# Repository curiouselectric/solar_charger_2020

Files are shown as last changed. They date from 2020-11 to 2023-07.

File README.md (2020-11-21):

# solar_charger_2020
This is a single cell 18650 Lithium Polymer battery charging circuit using one cell PV module.

Based upon the BQ24210 800mA, single-input, single cell Li-ion Solar battery charger from Texas Instruments:

https://www.ti.com/sitesearch/docs/universalsearch.tsp?searchTerm=BQ24210#q=BQ24210&t=everything&linkId=1

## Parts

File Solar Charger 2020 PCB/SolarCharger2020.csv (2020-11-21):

Source: | G:\My Drive\Work - Kits\PRODUCTS\Prototype\Solar Charger 2020\GITHUB\solar_charger_2020\Solar Charger 2020 PCB\SolarCharger2020.sch
Date: | 21/11/2020 16:56:55
Tool: | Eeschema (5.1.0)-1
Generator: | C:\Program Files\KiCad\bin\scripting\plugins/bom_csv_grouped_by_value.py
Component Count: | 16
Individual Components:
Item | Qty | Reference(s) | Value | LibPart | Footprint | Datasheet | Cost | Description | Manufacturer | Manufacturer Part No | Notes | Supplier 1 | Supplier 1 Cost | Supplier 1 Part No | Supplier 2 | Supplier 2 Cost | Supplier 2 Part No
 |  | BT1 | 18650 LiIon Cell | Device:Battery_Cell | REInnovationFootprint:TH_LiIon_Holder |  |  | 18650 PCB mount holder | ~ | ~ | ~ | eBay | 0.50 | http://www.ebay.co.uk/itm/122466718109 | ~ | ~ | ~
 |  | C1 | 1uF | Device:CP | REInnovationFootprint:SM1206 |  |  | ~ | ~ | ~ | ~ | ~ | 0.1 | ~ | ~ | ~ | ~
 |  | C2 | 1uF | Device:CP | REInnovationFootprint:SM1206 |  |  | ~ | ~ | ~ | ~ | ~ | 0.10 | ~ | ~ | ~ | ~
 |  | D2 | CHG | SolarCharger2020-rescue:LED-Device | REInnovationFootprint:SM0805_LED |  |  | ~ | ~ | ~ | ~ | ~ | 0.05 | ~ | ~ | ~ | ~
 |  | D3 | PG | SolarCharger2020-rescue:LED-Device | REInnovationFootprint:SM0805_LED |  |  | ~ | ~ | ~ | ~ | ~ | 0.05 | ~ | ~ | ~ | ~
 |  | F1 | 1A | Device:Fuse | REInnovationFootprint:SM_FSMD | ~
 |  | LG1 | LOGO1 | Connector_Generic:Conn_01x01 | CuriousElectric3:2019_011_16_CuriousElectricCompany_Logo_Round_Logo_No_words_KiCAD_10mm_PCBLogo
 |  | LG2 | LOGO2 | Connector_Generic:Conn_01x01 | CuriousElectric3:TCEC_Words_13mm
 |  | P1 | LiPo OUTPUT | Connector_Generic:Conn_01x02 | REInnovationFootprint:SIL_2_screw_+_JST_2mm
 |  | P3 | PV INPUT | Connector_Generic:Conn_01x02 | REInnovationFootprint:SIL_2_screw_+_JST_2mm
 |  | PCB1 | PCB | Connector_Generic:Conn_01x01 | REInnovationFootprint:PCB_SolarChargerPCB40x80
 |  | R1 | 1k | Device:R | REInnovationFootprint:SM0805 |  |  | ~ | ~ | ~ | ~ | ~ | 0.01 | ~ | ~ | ~ | ~
 |  | R2 | 100k | Device:R | REInnovationFootprint:SM0805 |  |  | ~ | ~ | ~ | ~ | ~ | 0.01 | ~ | ~ | ~ | ~
 |  | R3 | 2.2k | Device:R | REInnovationFootprint:SM0805 |  |  | ~ | ~ | ~ | ~ | ~ | 0.01 | ~ | ~ | ~ | ~
 |  | R4 | 2.2k | Device:R | REInnovationFootprint:SM0805 |  |  | ~ | ~ | ~ | ~ | ~ | 0.01 | ~ | ~ | ~ | ~
 |  | U1 | BQ24210 | matts_components:BQ24210 | REInnovationFootprint:SM_WSON-10-2x3 | http://www.ti.com/lit/ds/symlink/bq24210.pdf | ~ | LiIon Charger 800mA PV Input | Texas Instruments | BQ24210 | ~ | RS | 2.88 | 742-2836 | ~ | ~ | ~
Collated Components:
Item | Qty | Reference(s) | Value | LibPart | Footprint | Datasheet | Cost | Description | Manufacturer | Manufacturer Part No | Notes | Supplier 1 | Supplier 1 Cost | Supplier 1 Part No | Supplier 2 | Supplier 2 Cost | Supplier 2 Part No
1 | 1 | BT1 | 18650 LiIon Cell | Device:Battery_Cell | REInnovationFootprint:TH_LiIon_Holder |  |  | 18650 PCB mount holder | ~ | ~ | ~ | eBay | 0.50 | http://www.ebay.co.uk/itm/122466718109 | ~ | ~ | ~
2 | 2 | C1, C2 | 1uF | Device:CP | REInnovationFootprint:SM1206 |  |  | ~ | ~ | ~ | ~ | ~ | 0.1 | ~ | ~ | ~ | ~
3 | 1 | D2 | CHG | SolarCharger2020-rescue:LED-Device | REInnovationFootprint:SM0805_LED |  |  | ~ | ~ | ~ | ~ | ~ | 0.05 | ~ | ~ | ~ | ~
4 | 1 | D3 | PG | SolarCharger2020-rescue:LED-Device | REInnovationFootprint:SM0805_LED |  |  | ~ | ~ | ~ | ~ | ~ | 0.05 | ~ | ~ | ~ | ~
5 | 1 | F1 | 1A | Device:Fuse | REInnovationFootprint:SM_FSMD | ~
6 | 1 | LG1 | LOGO1 | Connector_Generic:Conn_01x01 | CuriousElectric3:2019_011_16_CuriousElectricCompany_Logo_Round_Logo_No_words_KiCAD_10mm_PCBLogo
7 | 1 | LG2 | LOGO2 | Connector_Generic:Conn_01x01 | CuriousElectric3:TCEC_Words_13mm
8 | 1 | P1 | LiPo OUTPUT | Connector_Generic:Conn_01x02 | REInnovationFootprint:SIL_2_screw_+_JST_2mm
9 | 1 | P3 | PV INPUT | Connector_Generic:Conn_01x02 | REInnovationFootprint:SIL_2_screw_+_JST_2mm
10 | 1 | PCB1 | PCB | Connector_Generic:Conn_01x01 | REInnovationFootprint:PCB_SolarChargerPCB40x80
11 | 1 | R1 | 1k | Device:R | REInnovationFootprint:SM0805 |  |  | ~ | ~ | ~ | ~ | ~ | 0.01 | ~ | ~ | ~ | ~
12 | 1 | R2 | 100k | Device:R | REInnovationFootprint:SM0805 |  |  | ~ | ~ | ~ | ~ | ~ | 0.01 | ~ | ~ | ~ | ~
13 | 2 | R3, R4 | 2.2k | Device:R | REInnovationFootprint:SM0805 |  |  | ~ | ~ | ~ | ~ | ~ | 0.01 | ~ | ~ | ~ | ~
14 | 1 | U1 | BQ24210 | matts_components:BQ24210 | REInnovationFootprint:SM_WSON-10-2x3 | http://www.ti.com/lit/ds/symlink/bq24210.pdf | ~ | LiIon Charger 800mA PV Input | Texas Instruments | BQ24210 | ~ | RS | 2.88 | 742-2836 | ~ | ~ | ~

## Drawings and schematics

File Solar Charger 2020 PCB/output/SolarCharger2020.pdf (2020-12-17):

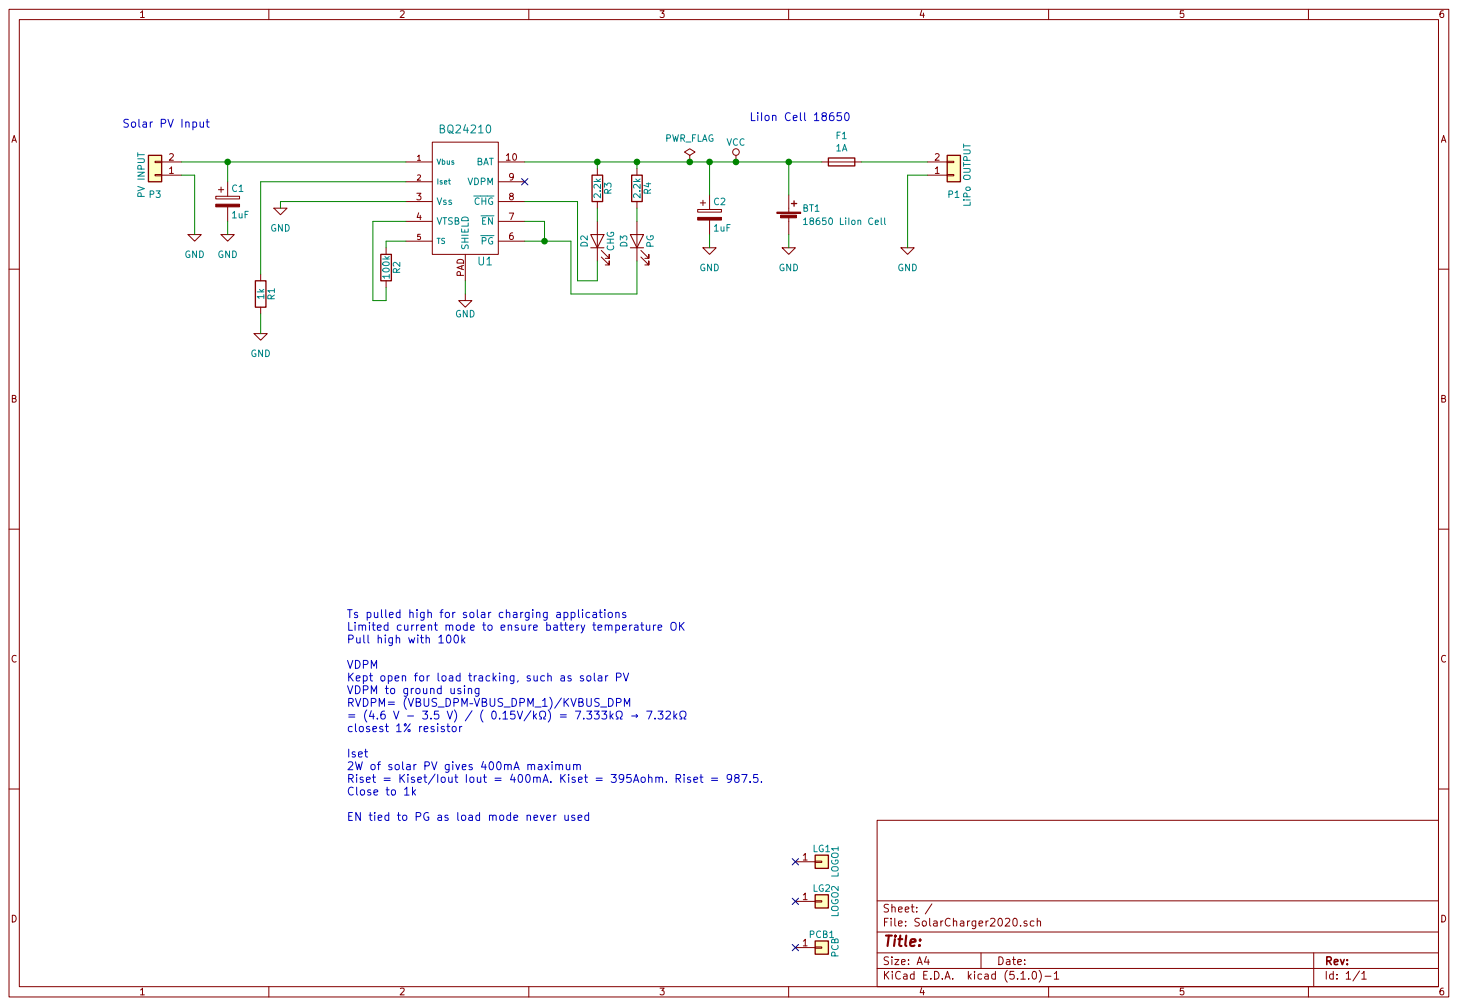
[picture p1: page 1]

Ts pulled high for solar charging applications
Limited current mode to ensure battery temperature OK
Pull high with 100k VDPM

Kept open for load tracking, such as solar PV
VDPM to ground using
RVDPM= (VBUS_DPMVBUS_DPM_1)/KVBUS_DPM

Iset 2W of solar PV gives 400mA maximum

Riset = Kiset/Iout Iout = 400mA. Kiset = 395Aohm. Riset = 987.5.
Close to 1k

EN tied to PG as load mode never used

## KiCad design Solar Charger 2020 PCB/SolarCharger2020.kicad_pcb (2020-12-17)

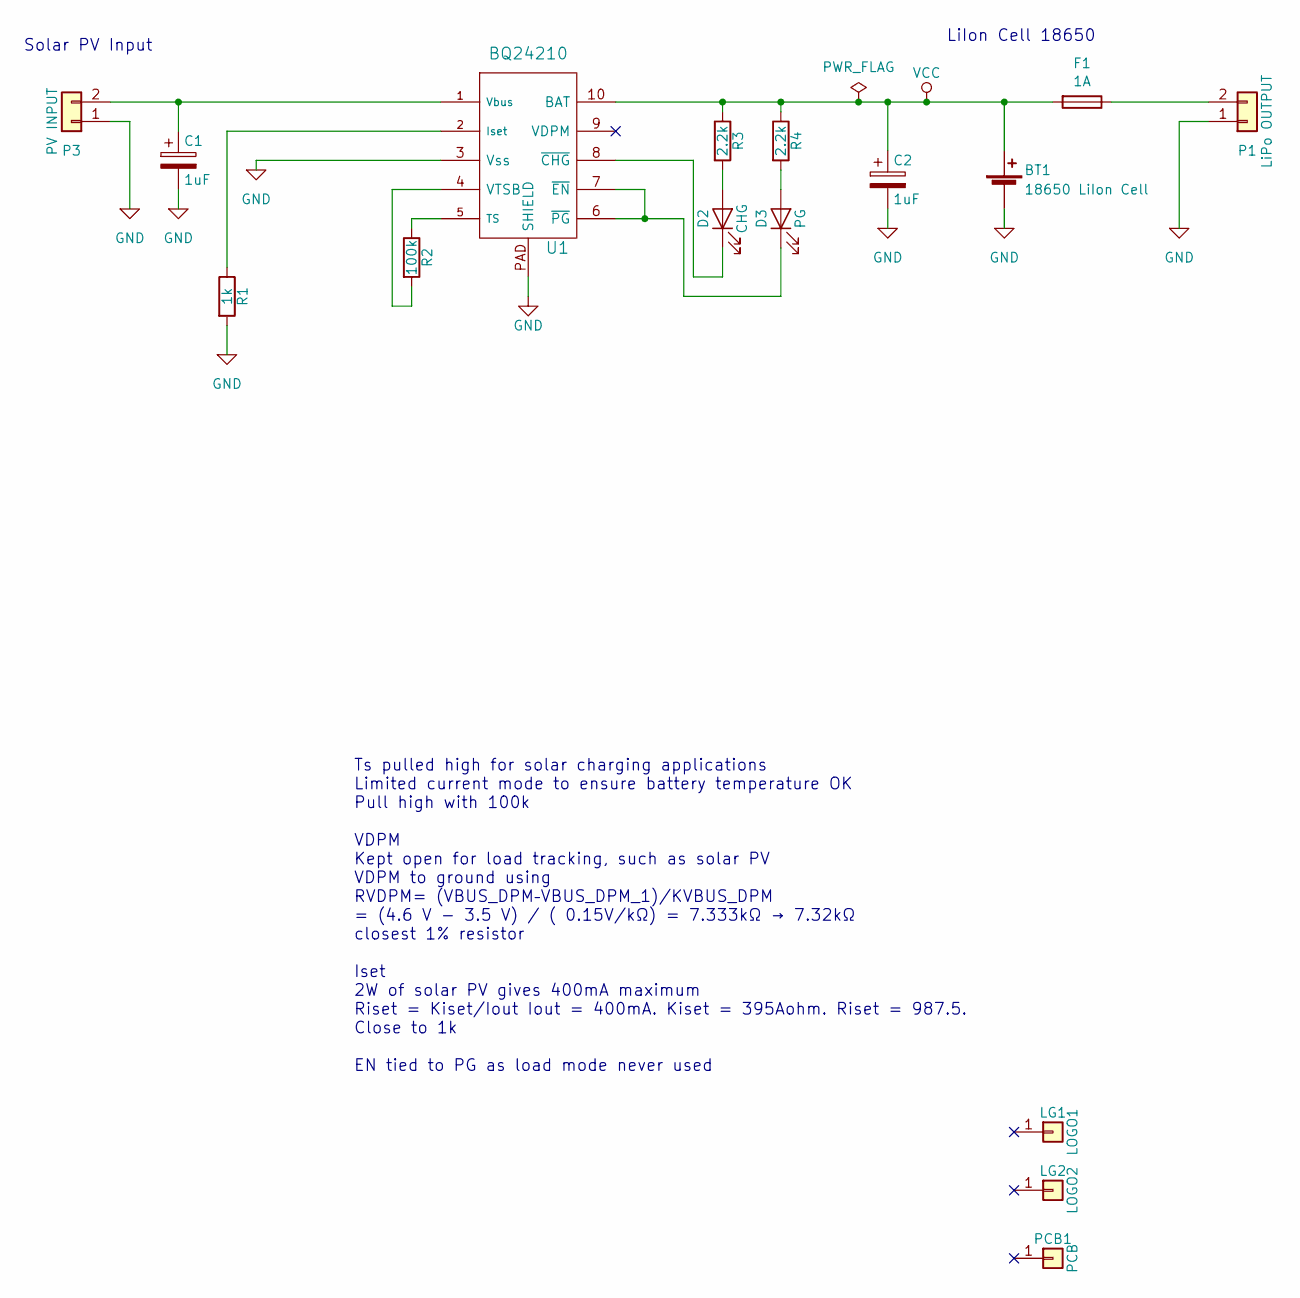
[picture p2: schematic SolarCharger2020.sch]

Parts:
BT1: 18650 LiIon Cell; TH_LiIon_Holder
C1, C2: 1uF; SM1206
D2: CHG; SM0805_LED
D3: PG; SM0805_LED
F1: 1A; SM_FSMD
LG1: LOGO1; 2019_011_16_CuriousElectricCompany_Logo_Round_Logo_No_words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
LG2: LOGO2; TCEC_Words_13mm
P1: LiPo OUTPUT; SIL_2_screw_+_JST_2mm
P3: PV INPUT; SIL_2_screw_+_JST_2mm
PCB1: PCB; PCB_SolarChargerPCB40x80
R1: 1k; SM0805
R2: 100k; SM0805
R3, R4: 2.2k; SM0805
U1: BQ24210; SM_WSON-10-2x3; Manufacturer Part No BQ24210

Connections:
GND: BT1.2 (-), C1.2, C2.2, P1.1, P3.1, R1.2, U1.3 (Vss), U1.PAD (SHIELD)
unnamed: C1.1, P3.2, U1.1 (Vbus)
unnamed: D2.1 (A), R3.2
unnamed: D2.2 (K), U1.8 (~CHG)
unnamed: D3.1 (A), R4.2
unnamed: D3.2 (K), U1.6 (~PG), U1.7 (~EN)
unnamed: F1.1, P1.2
unnamed: R1.1, U1.2 (Iset)
unnamed: R2.1, U1.5 (TS)
unnamed: R2.2, U1.4 (VTSB)
VCC: BT1.1 (+), C2.1, F1.2, R3.1, R4.1, U1.10 (BAT)

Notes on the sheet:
Solar PV Input
LiIon Cell 18650
Ts pulled high for solar charging applications Limited current mode to ensure battery temperature OK Pull high with 100k VDPM Kept open for load tracking, such as solar PV VDPM to ground using RVDPM= (VBUS_DPM–VBUS_DPM_1)/KVBUS_DPM = (4.6 V - 3.5 V) / ( 0.15V/kΩ) = 7.333kΩ → 7.32kΩ closest 1% resis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

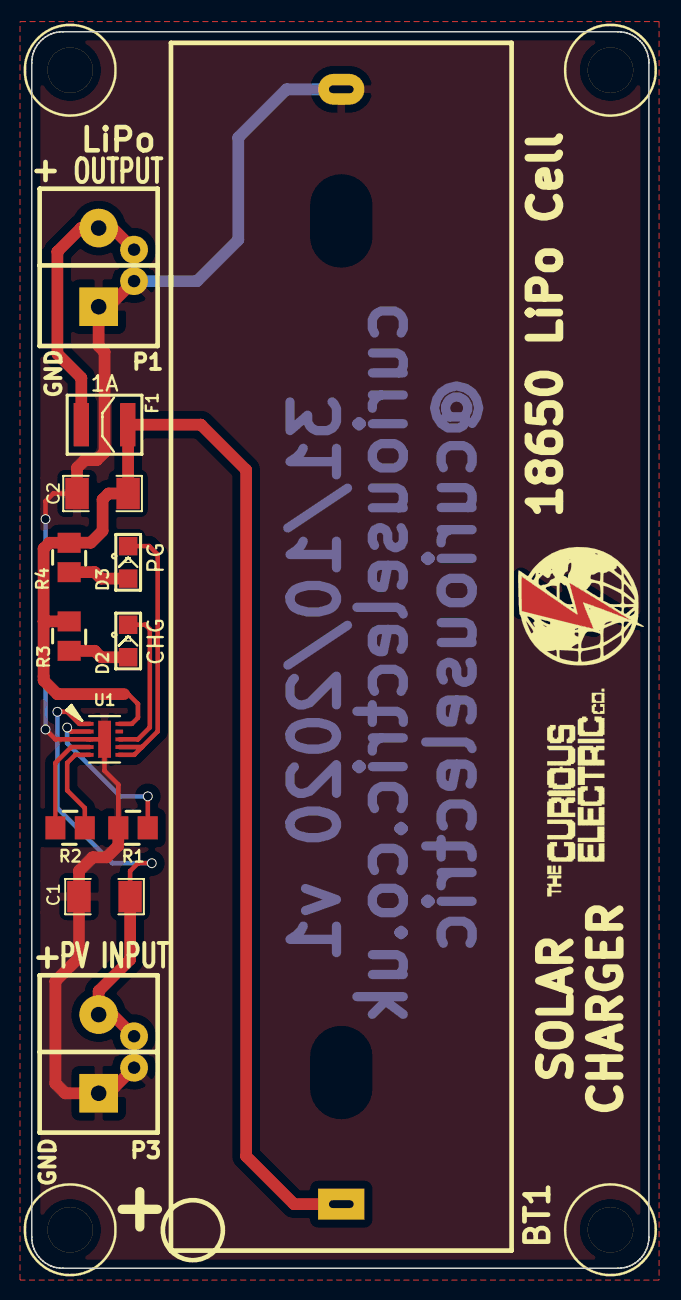
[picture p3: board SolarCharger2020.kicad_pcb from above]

Board: 2 copper layers, 39.9 x 79.9 mm, 16 parts (1 on the bottom side), 11 nets.

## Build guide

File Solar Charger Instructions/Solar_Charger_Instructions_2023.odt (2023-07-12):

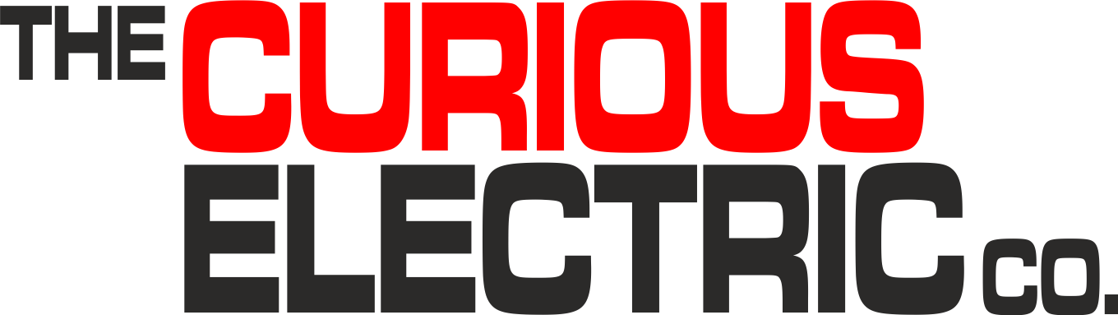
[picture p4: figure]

| BQ24210 Solar Charger Instructions

Date: | 12/7/2023 | Version: | 1.1 | By: | Matt Little

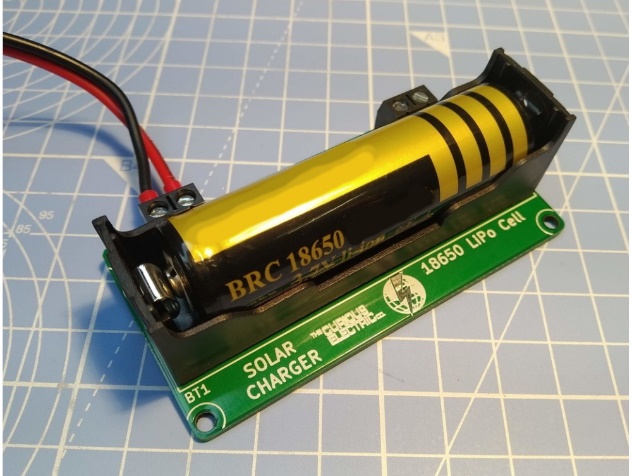
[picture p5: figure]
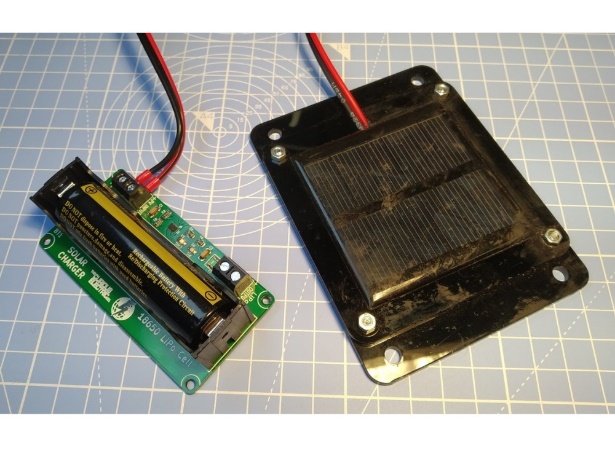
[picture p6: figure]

This is a solar lithium-ion single cell battery charger unit using the Texas Instruments IC BQ24210 (http://www.ti.com/product/BQ24210).

It is designed to run small electronics projects (such as data-loggers and environmental monitoring units) in places where there is no supply of electricity. I designed it originally to run a small weather station which monitored and wirelessly sent back data to a base station.

This is a 800mA single-input, single cell Lithium Ion battery charger IC. The datasheet is available here: http://www.ti.com/lit/ds/slusa76b/slusa76b.pdf

This IC is pre-soldered, as it is a very small surface-mounted package, along with all the other main components.

You only need to solder the battery holder and screw terminals.

You need to add a small solar panel with an output voltage of (ideally) between 3.5 and 7V DC. I use modules with 5.5V output and 200mA.

Note: The 18650 lithium ion Cell is NOT supplied!

Note: The solar panel is NOT supplied!

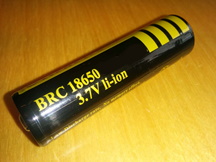
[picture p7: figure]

*Note: We do NOT supply the 18650 size lithium ion cell. This is due to shipping restrictions. These cells are usually available locally.

We suggest getting a good-quality cell with a decent capacity (in the region of 2000-3000mAh).

# Parts included:

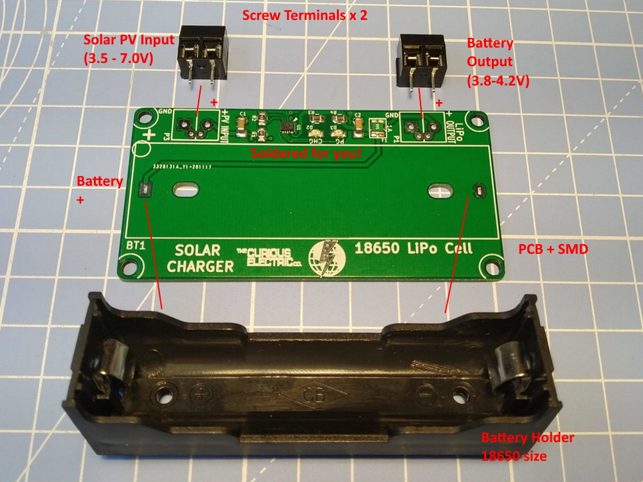
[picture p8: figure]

# Kit Parts List:

Ref | Item | Quantity | Ref | Item | Quantity
BT1 | 18650 Cell Holder | 1 | PCB | PCB with soldered components | 1
P1, P3 | Screw Terminals | 2

# Tools required:

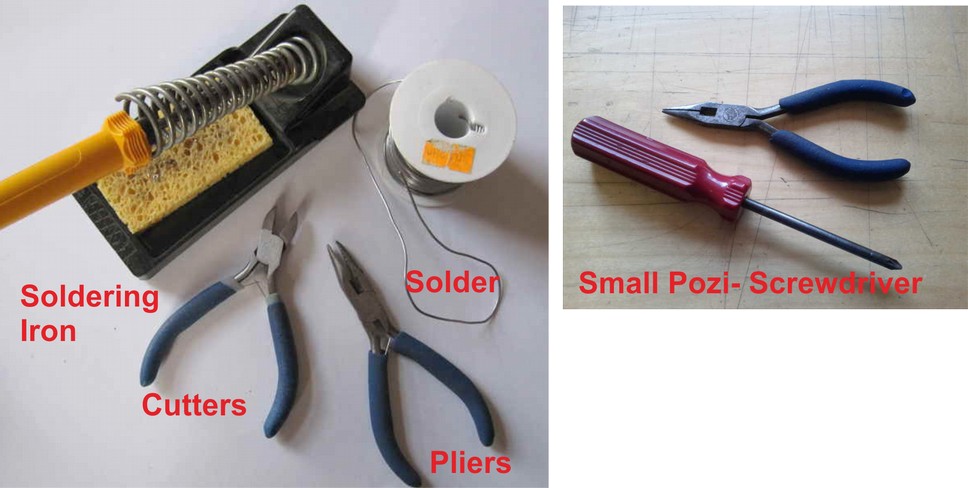
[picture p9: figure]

| | Long-nosed Pliers
Soldering Iron | | Posi-drive Screwdriver
Solder
Side cutters

# Instructions:

Step: 1 | Solder the components

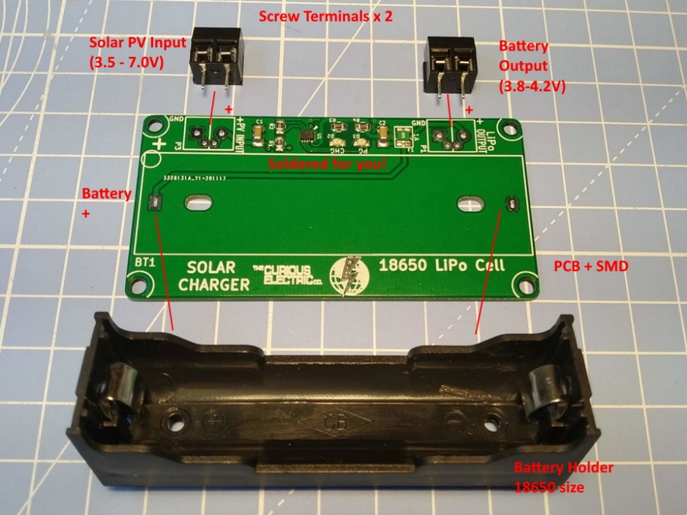
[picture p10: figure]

| | Want to solder P1 and P3 with the terminals facing out away from the PCB. There are holes to add a JST type connector (but socket not supplied). Place the battery holder in the component marked BT1. Check that the +ve terminal aligns with the + on the silk screen of the PCB.

Step: 2 | Add an 18650 lithium-ion Cell

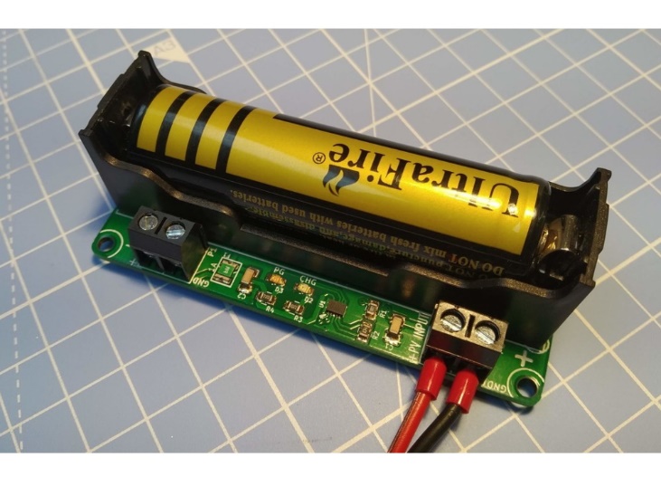
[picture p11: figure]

Double check the polarity!

Step: 3 | Add a solar PV module

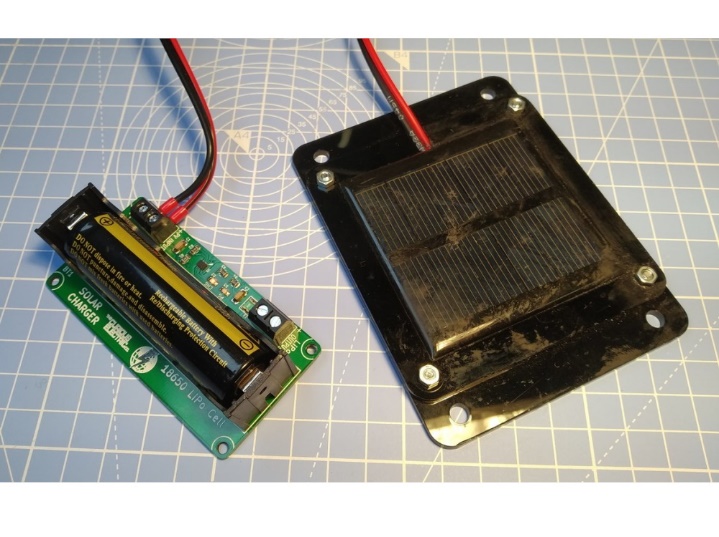
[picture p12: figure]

| | Add a small solar panel wired to the solar input. You can power your circuit from the power output terminal. This is protected by a 500 mA resetting fuse (with trip current of 1A).

# Testing & Operation

You will need a small solar panel, with an output voltage of between 3.5-7V DC. The max solar PV voltage is 18V DC. The max current output is set to 400mA, so a solar panel with an output of around 400mA is most suitable. I use a 5.5V panel with 200mA output and it works well.

Initially the battery may be totally discharged.

Place the unit in the sun for a while. The red LEDs D1 and D2 should light after a while. This may take 5-10mins in weak sunlight.

- The PG LED shows that there is enough sunlight to power the IC.
- The CHG LED shows that the battery is charging.

A 5000mAh battery will take around 14 hours of strong sunlight to fully charge the battery. This would be around 4 days in the summer and around 14 days (!) in winter (in the UK!) to fully charge the battery from empty.

The output power is direct from the lithium cell, in which case this will be a variable voltage between around 3.7V to 4.2V. This is protected by a 500mA / 1A trip resetting fuse.

This unit is designed as a building block for your projects. It has many uses - from powering data-logging systems to emergency recharging of mobile devices.

Note: The weather and available sunlight is variable, so there are no definite rules about recharging times. If outside on an average UK summers day the batteries will be fully charged in around 3-4 days. If outside on an average UK winters day then the batteries will be fully charged in 10-15 days. If used behind a window, the glass will affect the available sunlight and increase the recharge times by a factor of at least 50%.

The circuit diagram shows the components. Some notes from the data sheet include:

- Ts is pulled high (with 100k) for solar charging applications

Limited current mode to ensure battery temperature OK

- VDPM is kept open for load tracking, such as solar PV
- The max current setpoint (Iset) is set by R1

2W of solar PV gives 400mA maximum

Riset = Kiset/Iout Iout = 400mA. Kiset = 395Aohm. Riset = 987.5. (1k used)

- EN tied to PG as load mode never used

Full design files for the PCB and these instructions and datasheets are available in the github repository for this project here:

https://github.com/curiouselectric/solar_charger_2020

# Contact details:

This kit has been designed and produced by:

The Curious Electric Company

hello@curiouselectric.co.uk

www.curiouselectric.co.uk

We would like you to be happy with this kit. If you are not happy for any reason, then please contact us and we will help to sort it out.

Please email hello@curiouselectric.co.uk with any questions or comments.

Please tweet us at @curiouselectric

If any parts are missing from your kit then please email hello@curiouselectric.co.uk with details, including when and where the kit was purchased.

More technical information can be found via www.curiouselectric.co.uk

# Circuit Schematic:

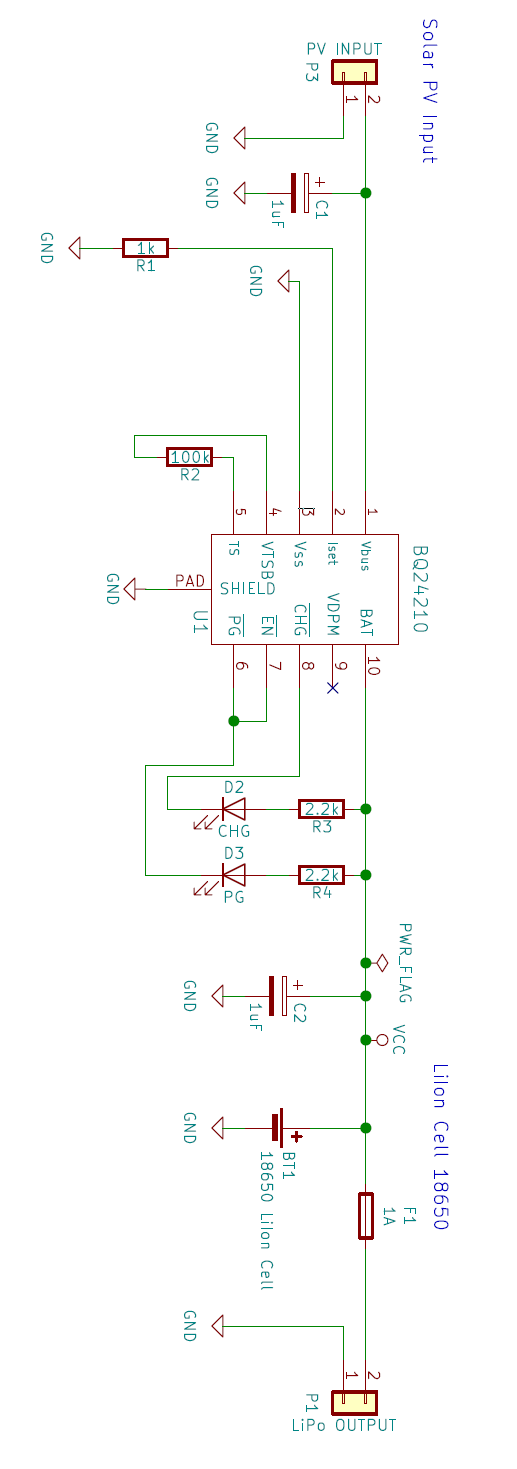
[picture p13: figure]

# PCB

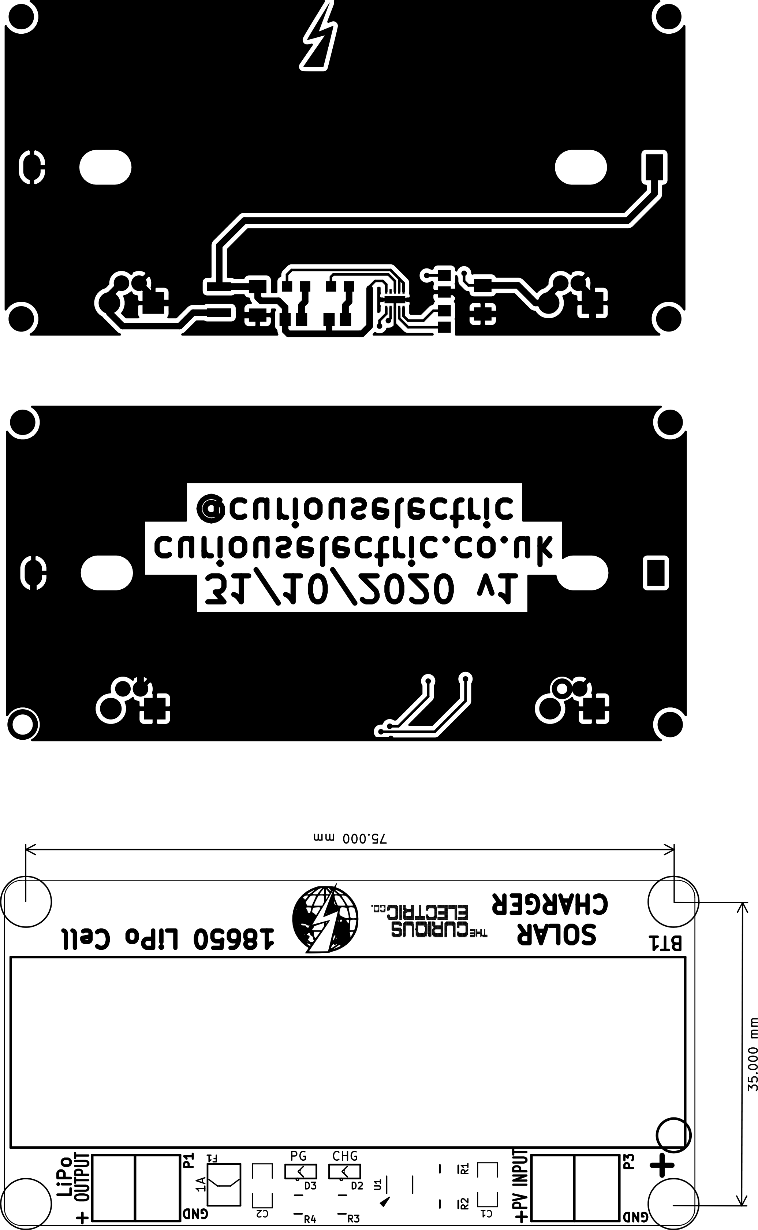
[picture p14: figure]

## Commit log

2020-11-21 Full upload of PCB files and instructions
    [SolarCharger2020-B_Cu.gbr, SolarCharger2020-B_Mask.gbr, SolarCharger2020-B_Paste.gbr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]
2020-11-21 Small update
    [SolarCharger2020.csv, SolarCharger2020.xlsx]
2020-12-17 Updated instructions
    [SolarCharger2020.kicad_pcb, SolarCharger2020.sch]
